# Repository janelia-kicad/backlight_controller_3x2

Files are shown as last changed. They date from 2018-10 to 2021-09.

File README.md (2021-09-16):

- [Repository Information](#org4660580)
  - [Description](#org6dcabe7)
- [Images](#org285c25f)
- [Schematic](#orgf1630ab)
- [Gerbers](#org91c6de4)
- [Bill of Materials](#orgdd32f43)
  - [PCB Parts](#org0175e16)
  - [Supplemental Parts](#orgda2eed9)
  - [Vendor Parts Lists](#orgb926b52)
- [Supplemental Documentation](#org7f741fd)
  - [Assembly Instructions](#orgb29884f)

# Repository Information

-   **Name:** backlight\_controller\_3x2
-   **Version:** 1.2
-   **License:** Open-Source Hardware
-   **URL:** <https://github.com/janelia-kicad/backlight_controller_3x2>
-   **Author:** Peter Polidoro
-   **Email:** peter@polidoro.io

## Description

This board controls one Smart Vision backlight with IR and visible channels plus additional high and low power channel outputs.

# Images

# Schematic

[./schematic/backlight\_controller\_3x2.pdf](./schematic/backlight_controller_3x2.pdf)

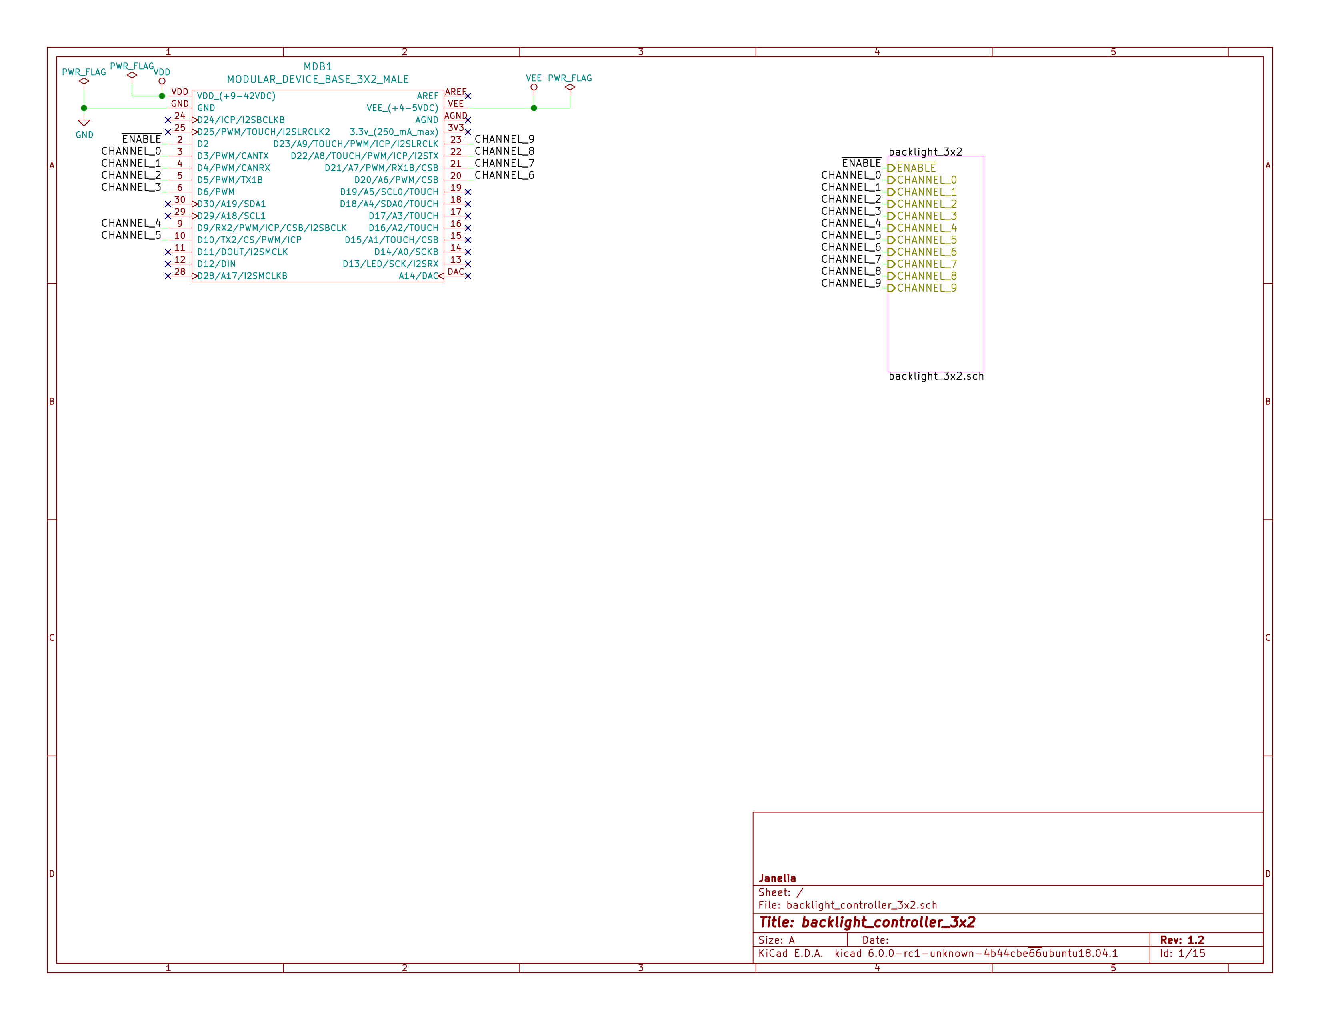
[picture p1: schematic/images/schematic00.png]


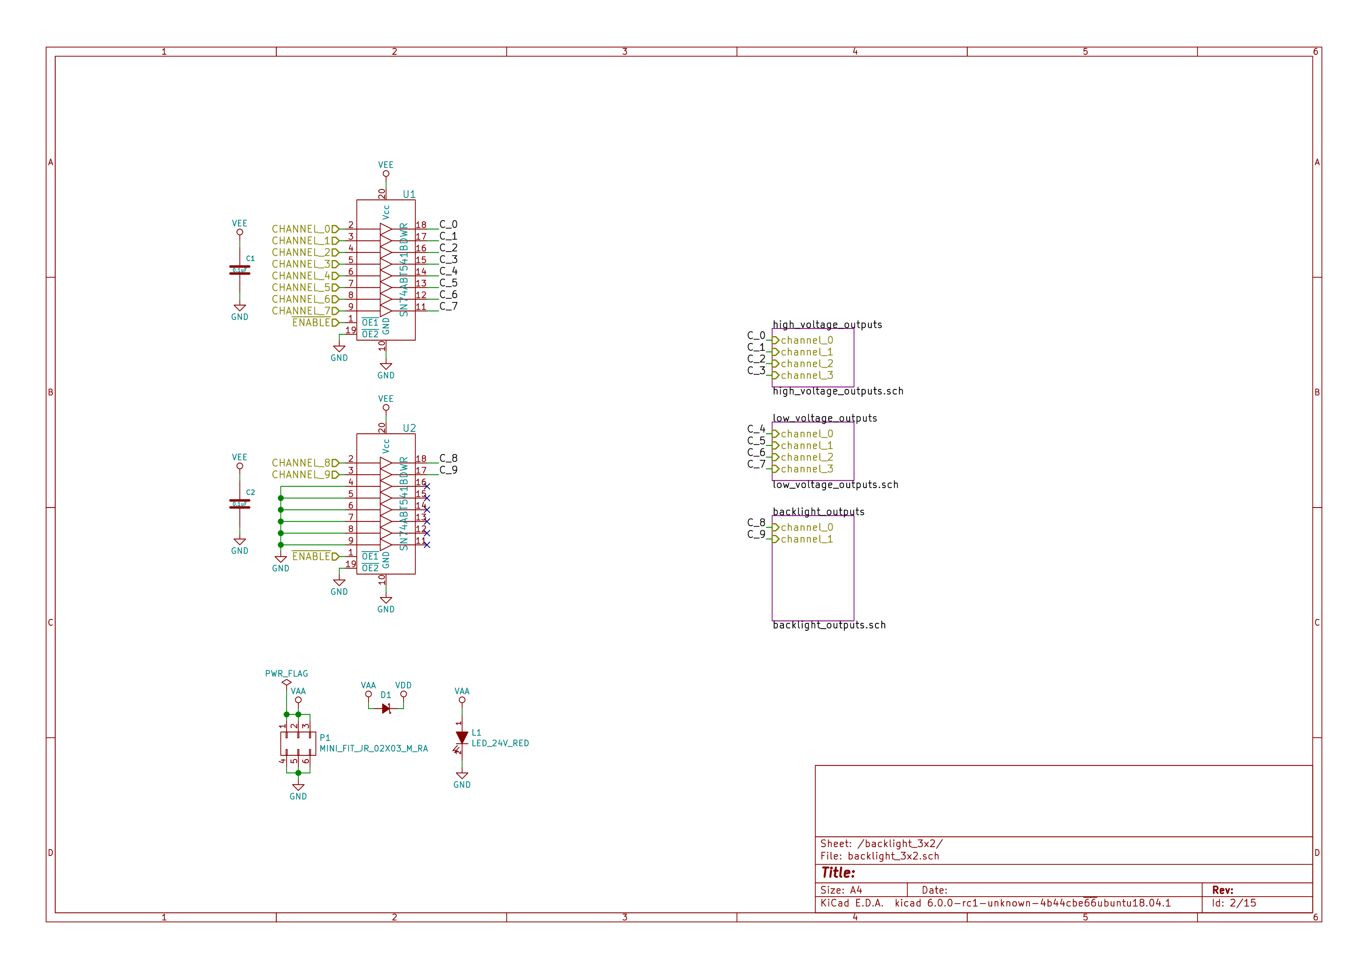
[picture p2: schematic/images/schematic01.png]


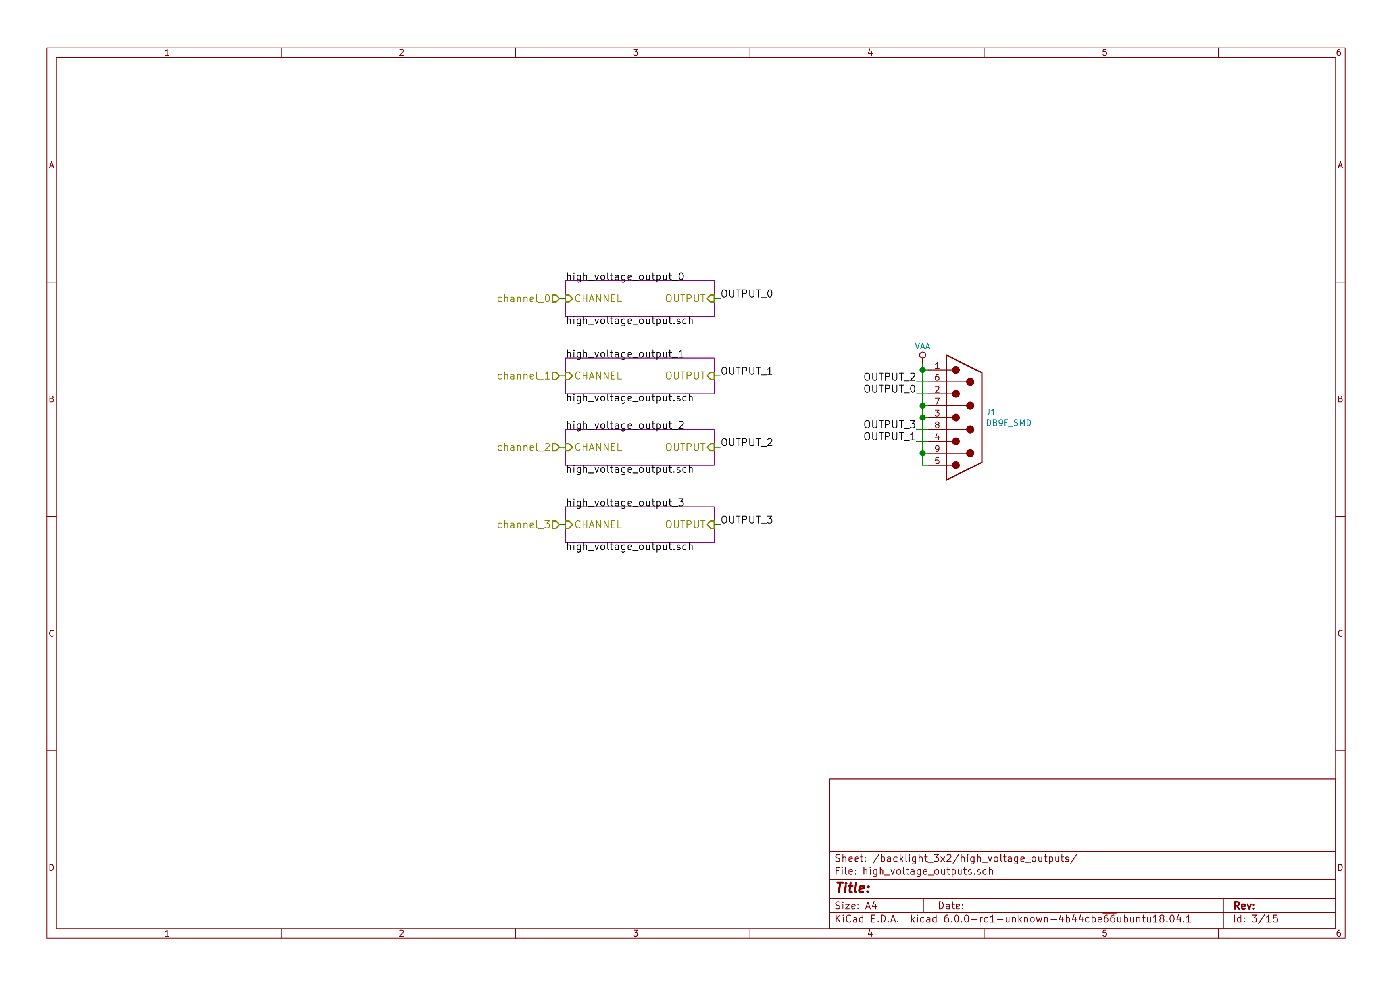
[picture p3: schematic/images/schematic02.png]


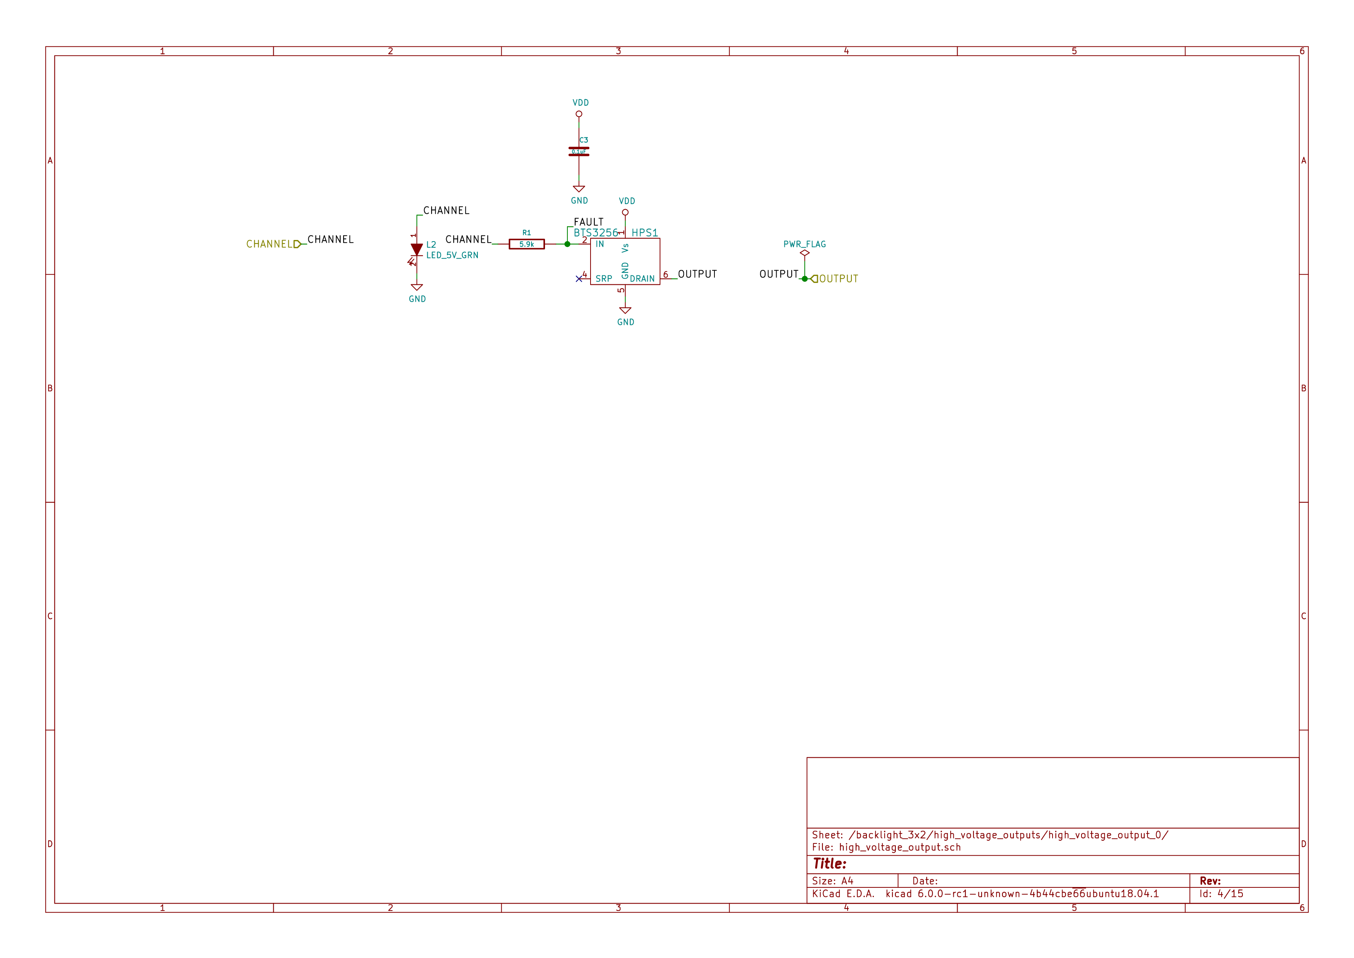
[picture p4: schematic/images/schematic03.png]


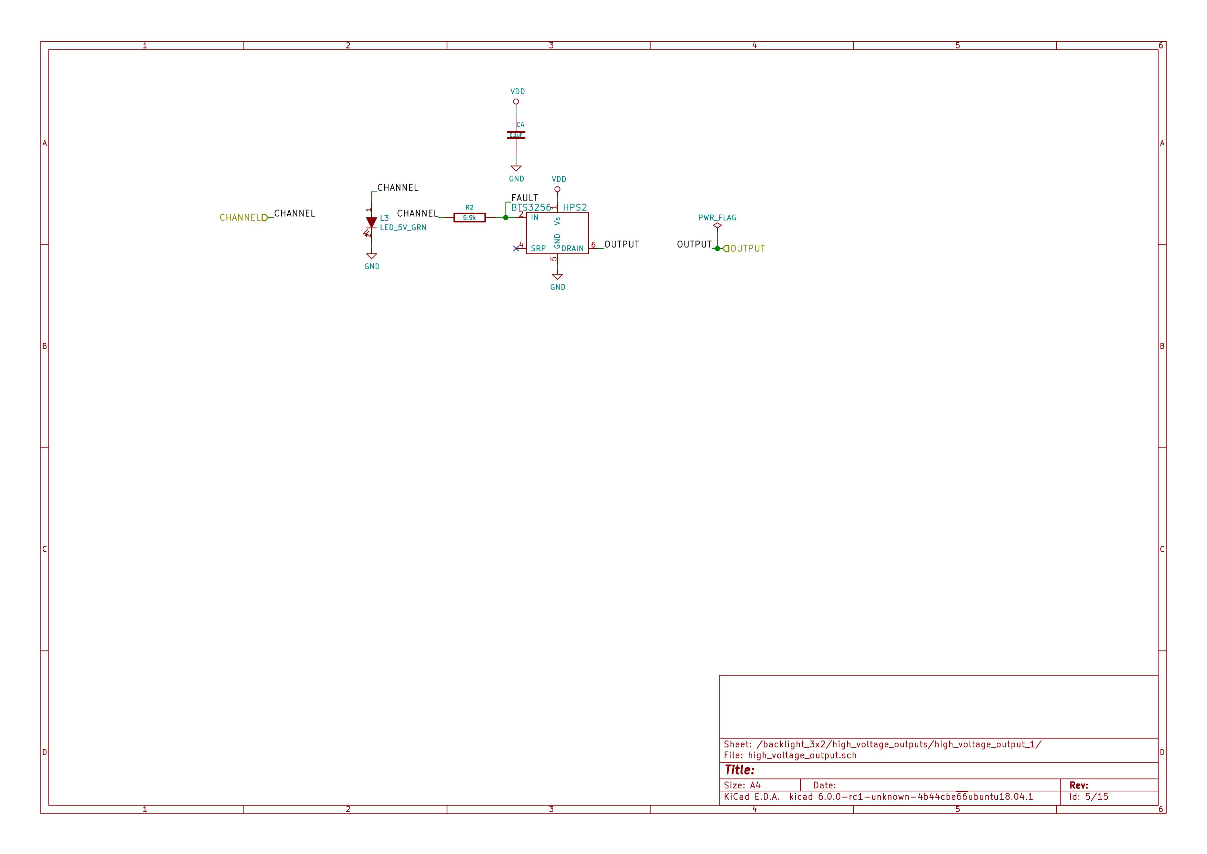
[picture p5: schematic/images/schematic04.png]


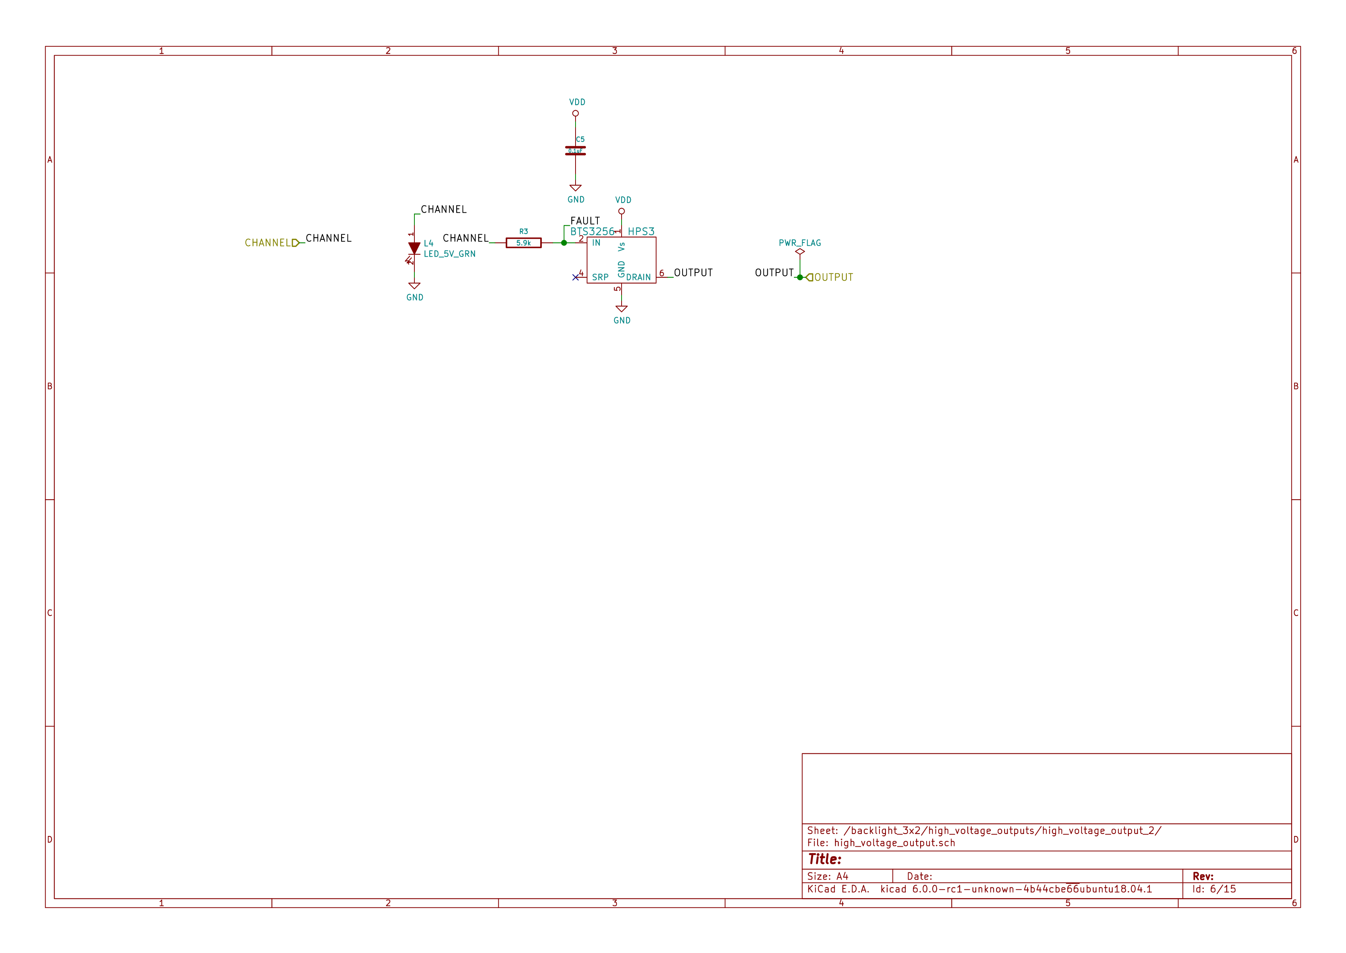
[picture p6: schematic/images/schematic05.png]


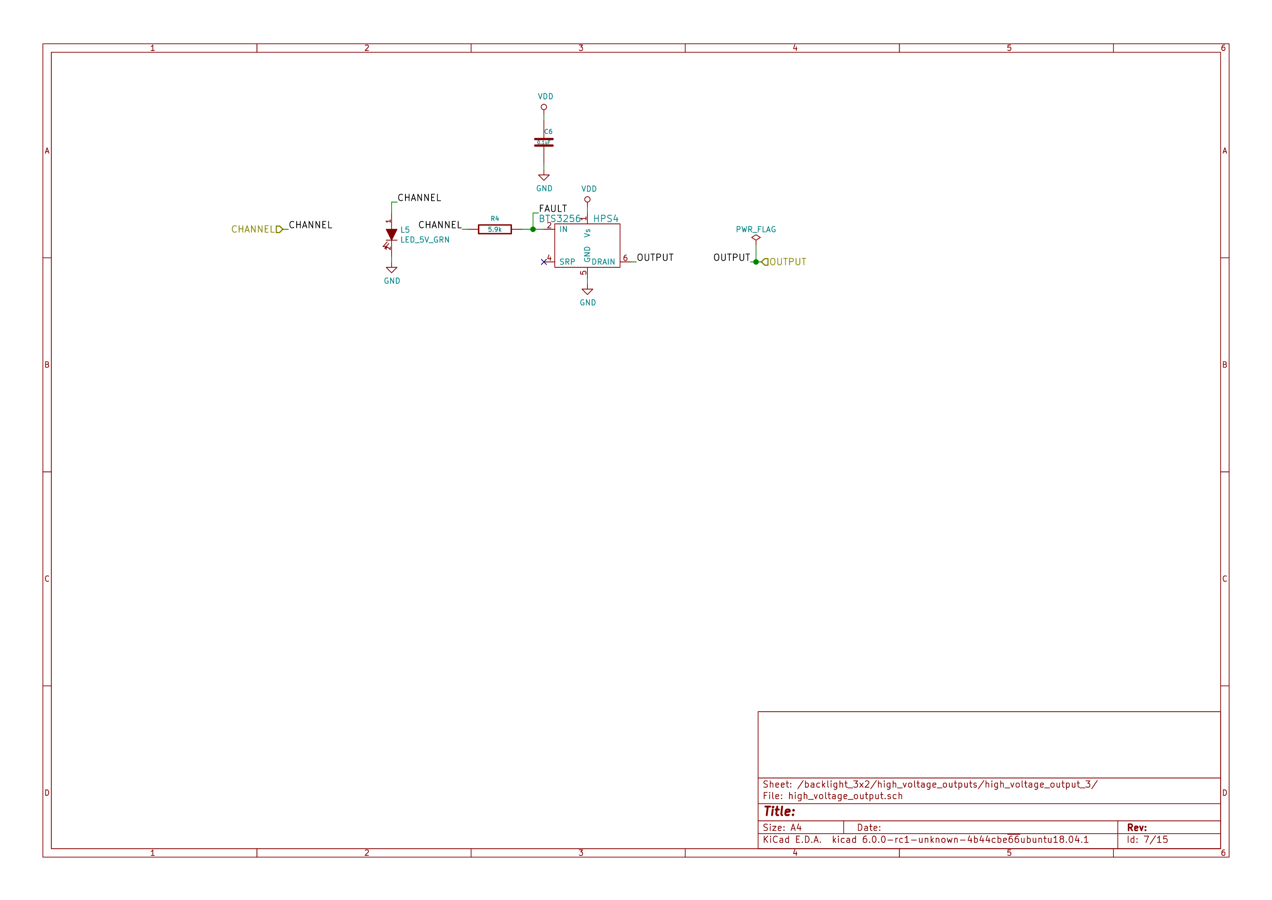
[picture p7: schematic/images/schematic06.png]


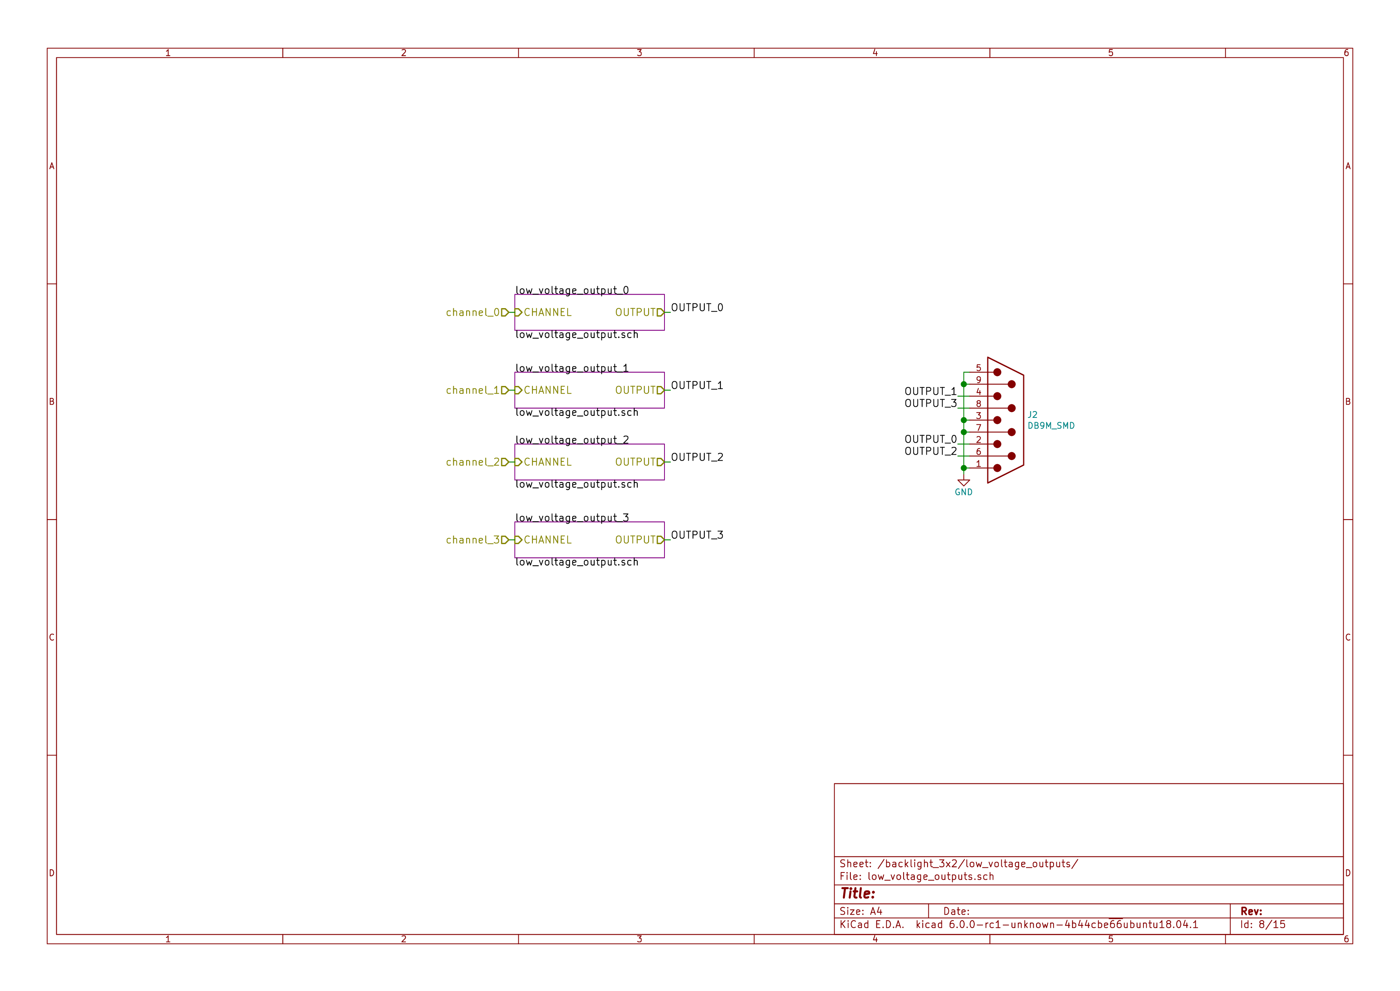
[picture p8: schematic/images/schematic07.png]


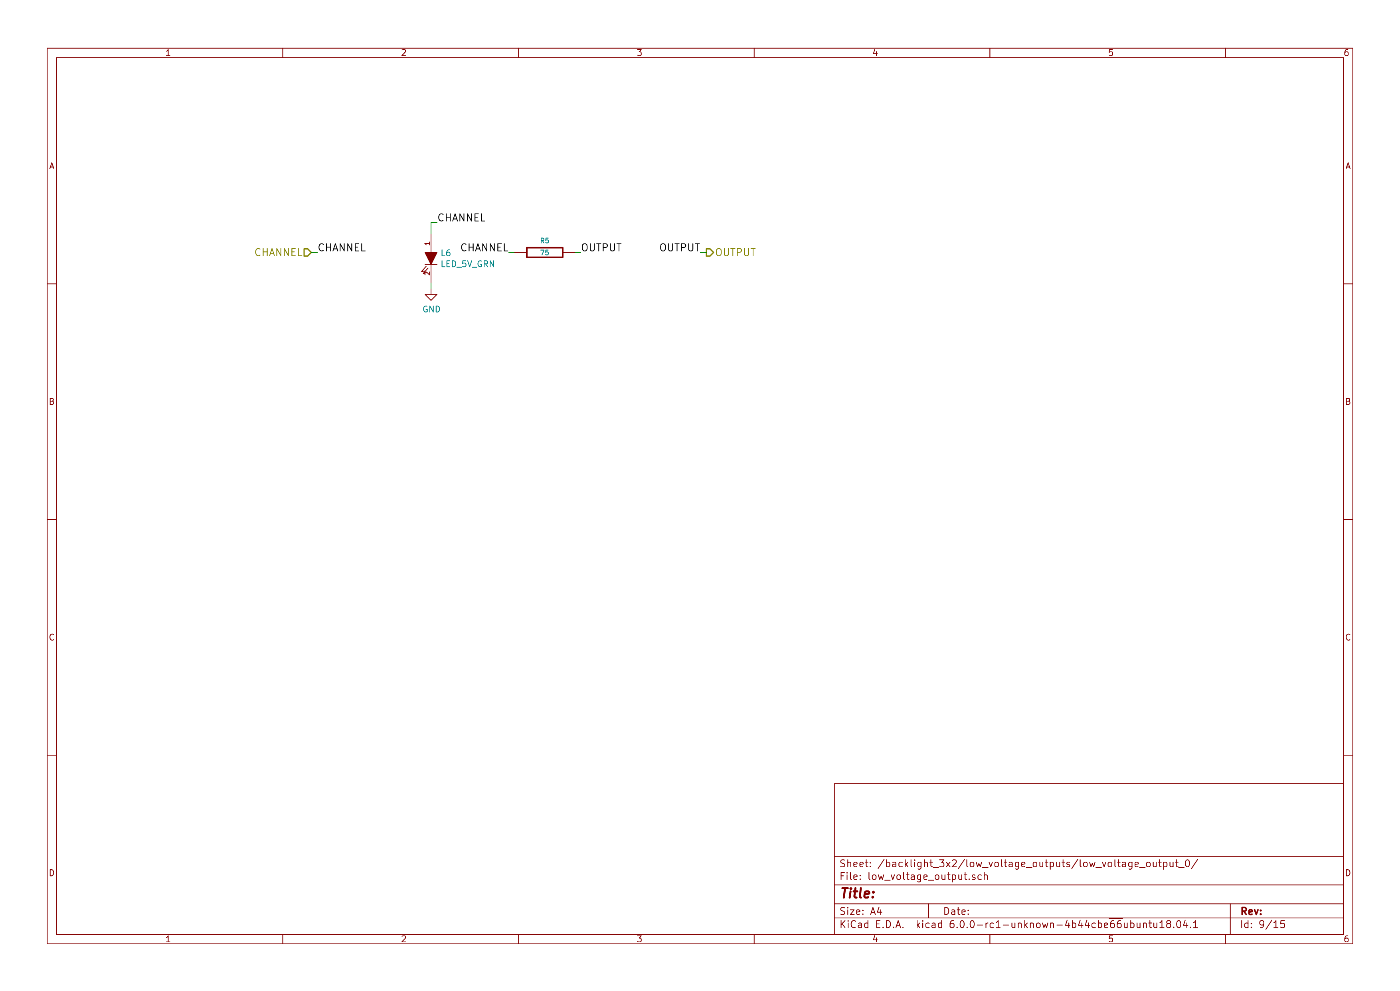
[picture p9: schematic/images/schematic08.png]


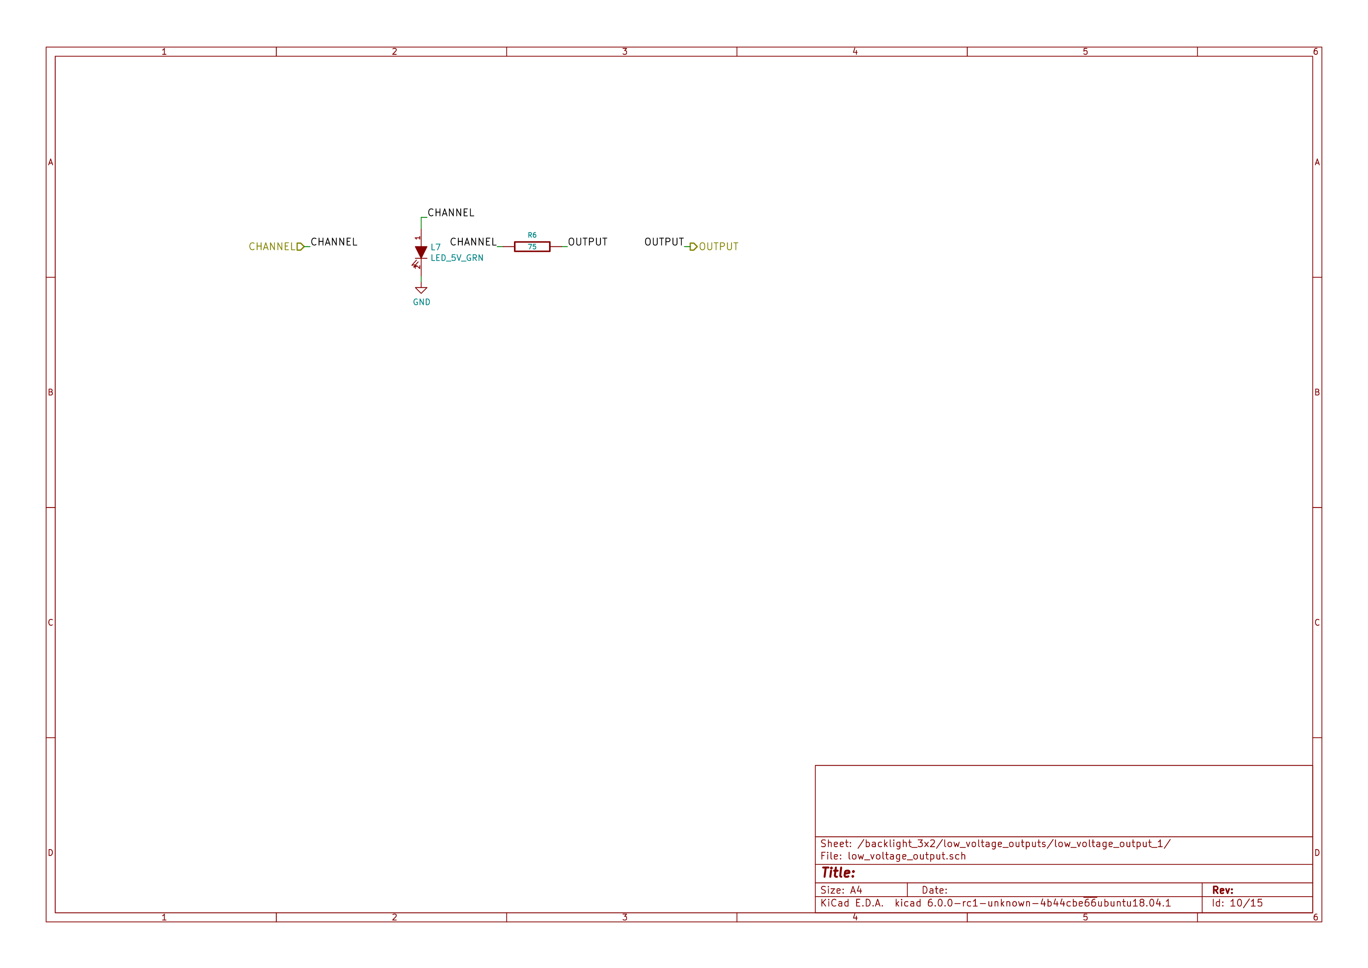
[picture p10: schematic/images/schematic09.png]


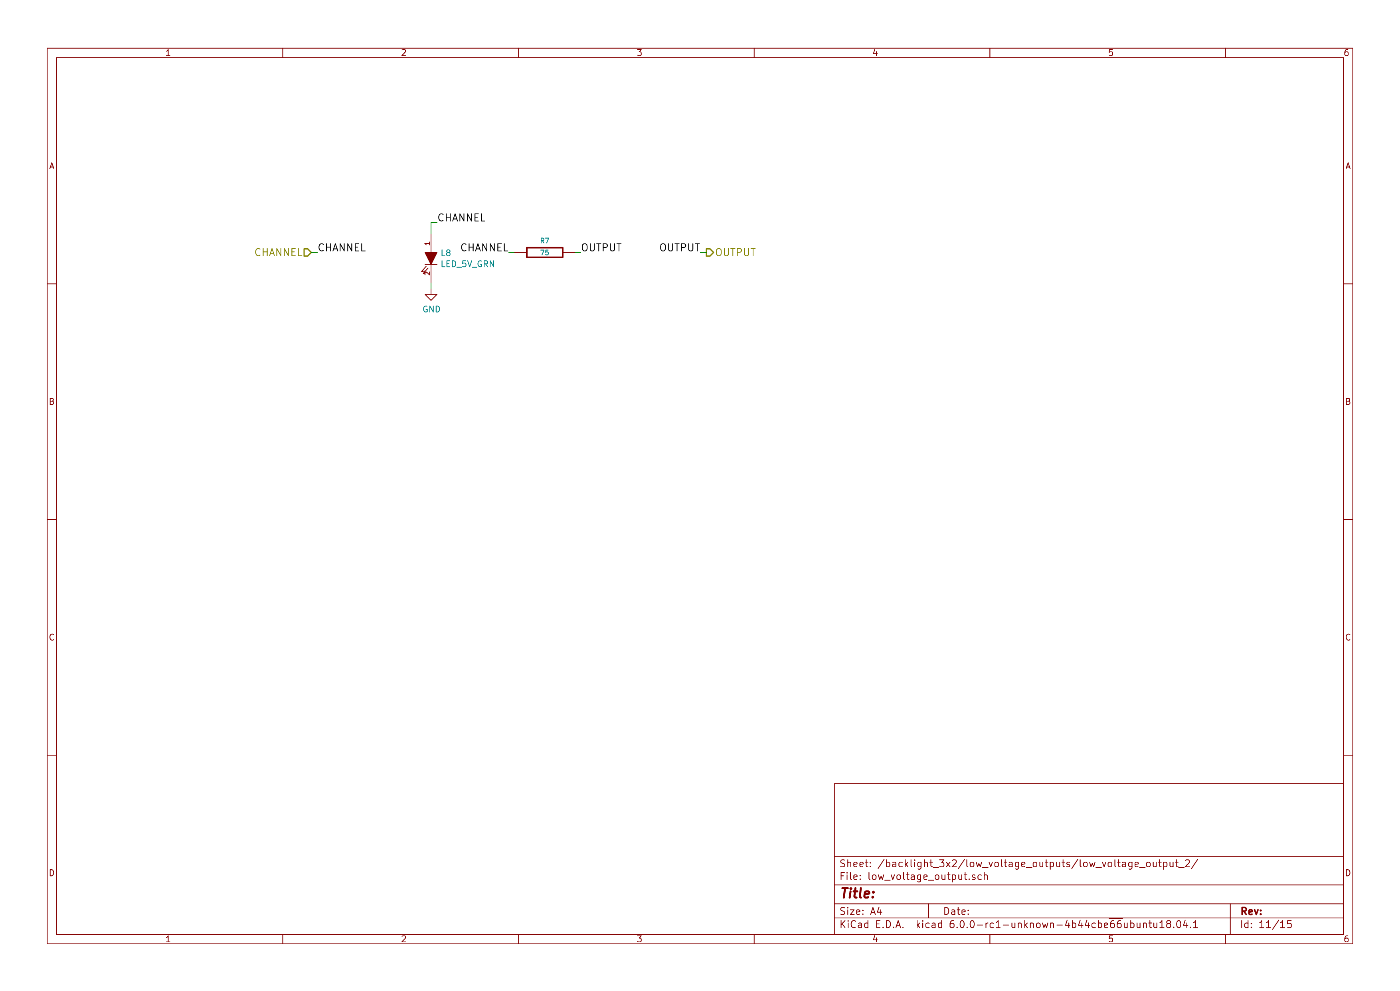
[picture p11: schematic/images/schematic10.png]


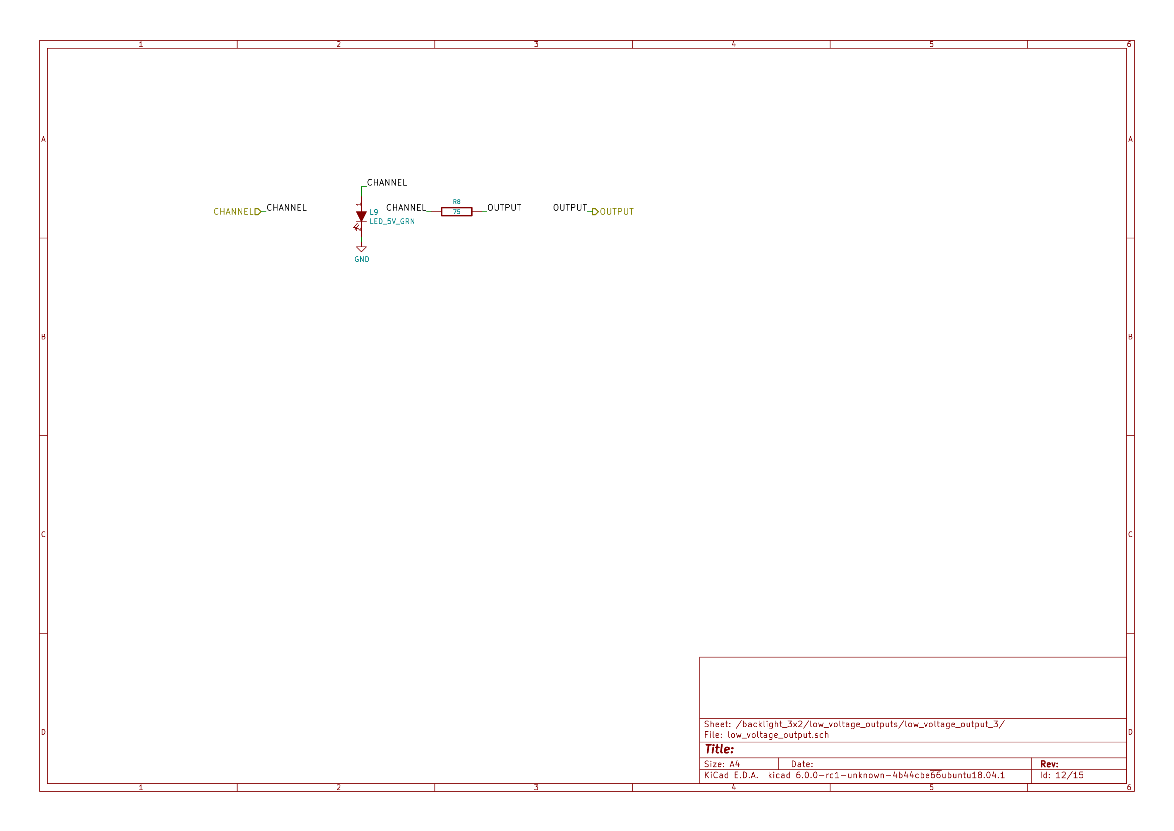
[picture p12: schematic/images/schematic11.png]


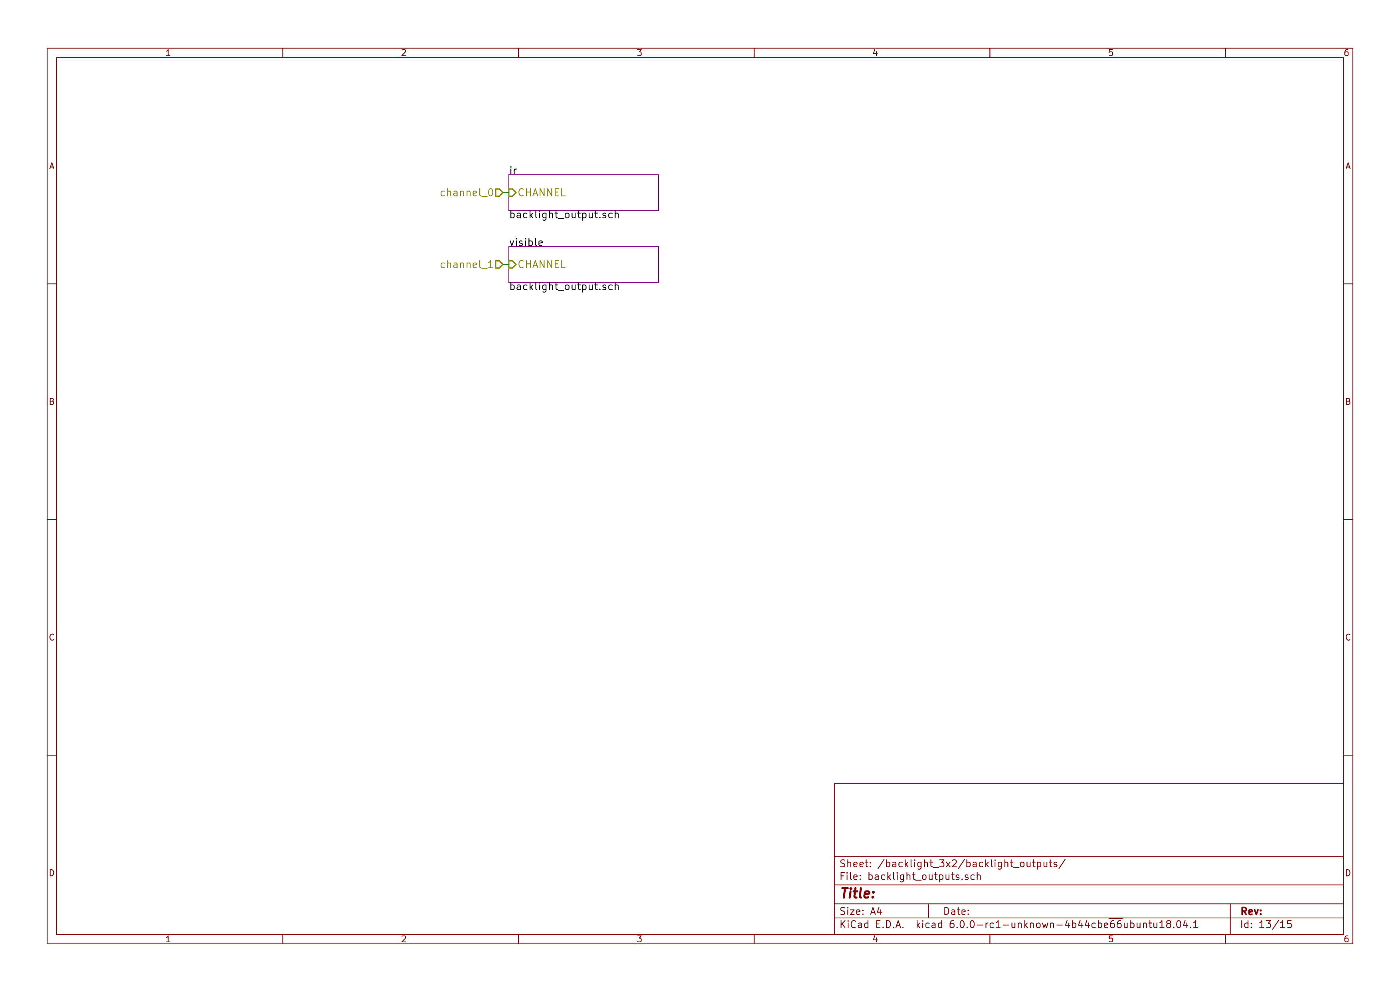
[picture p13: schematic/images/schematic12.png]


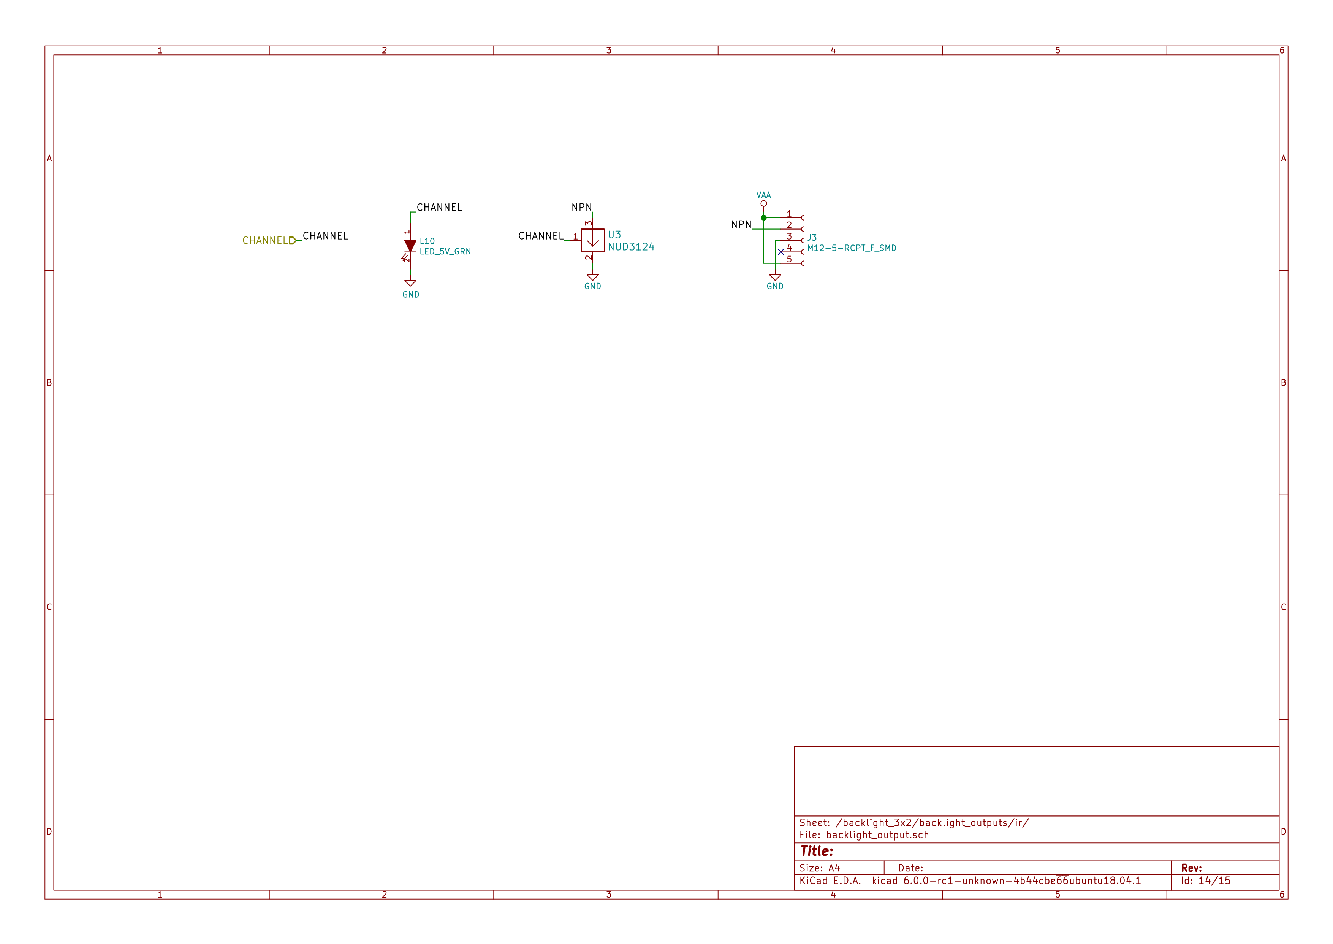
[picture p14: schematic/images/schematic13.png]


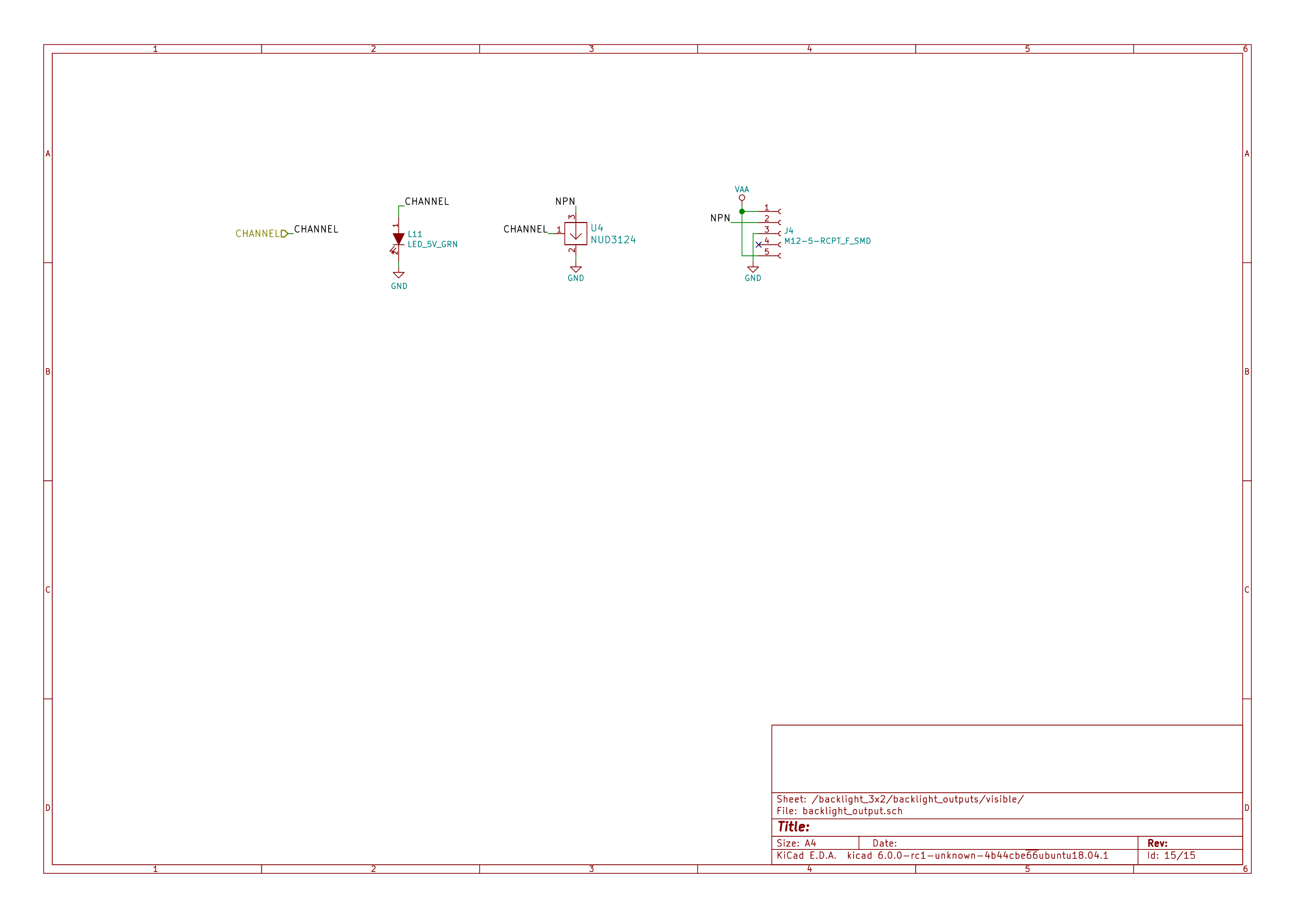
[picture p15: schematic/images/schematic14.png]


# Gerbers

Send gerbers zip file to your favorite PCB manufacturer for fabrication.

[./gerbers/backlight\_controller\_3x2\_v1.2.zip](./gerbers/backlight_controller_3x2_v1.2.zip)

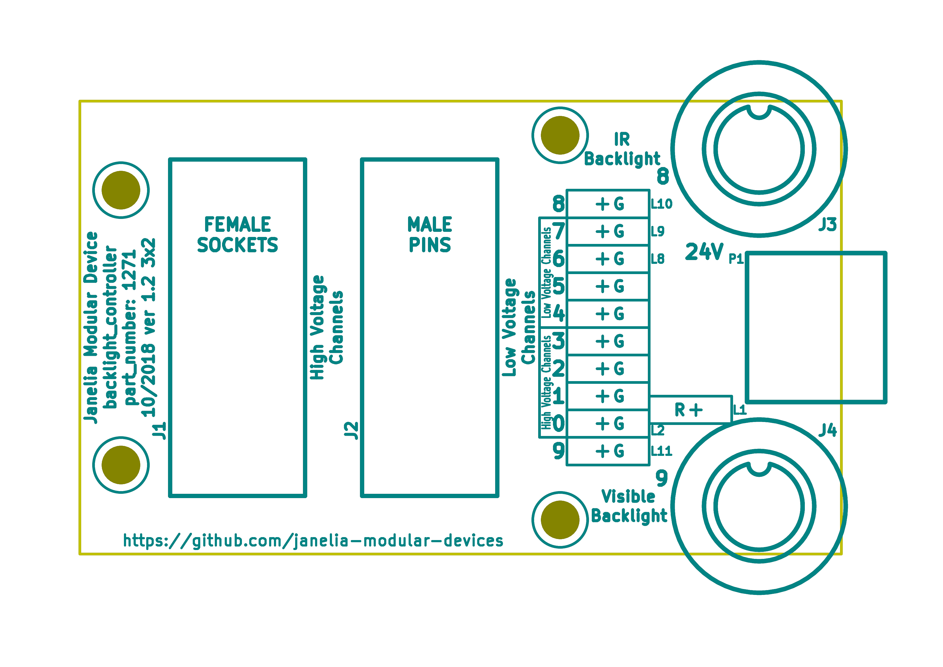
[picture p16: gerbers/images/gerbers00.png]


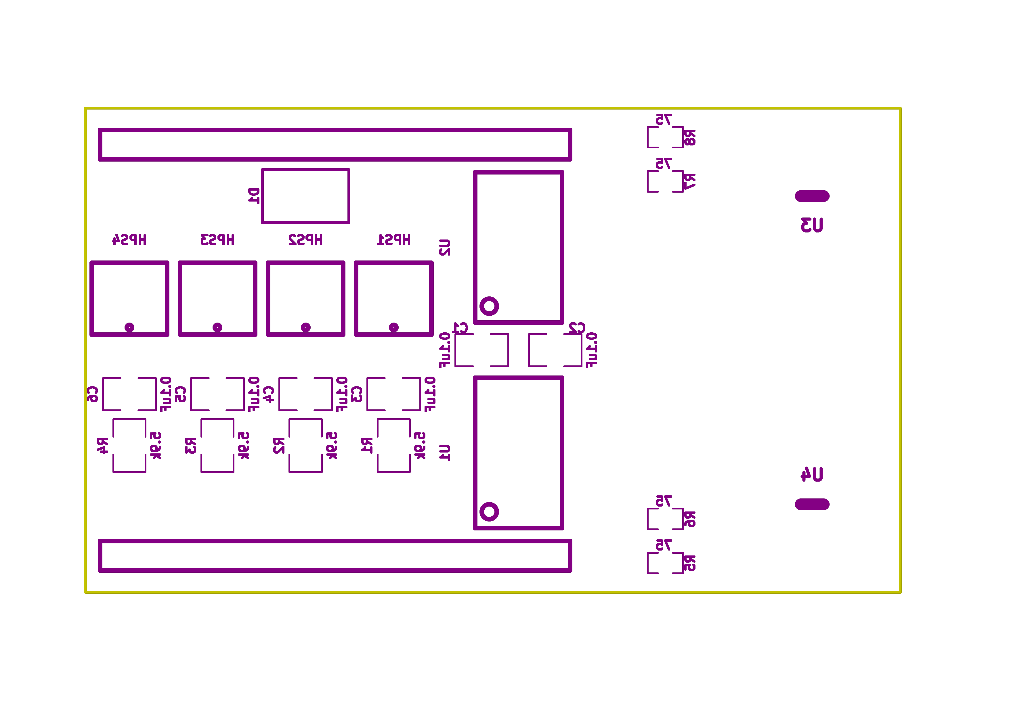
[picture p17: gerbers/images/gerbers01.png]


# Bill of Materials

## PCB Parts

| Item | Reference(s) | Quantity | PartNumber | Vendor  | Description |
|---- |--- |--- |--- |--- |--- |
| 1 | C1 C2 C3 C4 C5 C6 | 6 | 399-13229-1-ND | digikey | CAP CER 0.1UF 50V 10% X7R 1210 |
| 2 | D1 | 1 | 568-11697-1-ND | digikey | DIODE SCHOTTKY 45V 10A CFP15 |
| 3 | HPS1 HPS2 HPS3 HPS4 | 4 | BTS3256DAUMA1CT-ND | digikey | IC SWITCH SMART LOWSIDE TO252-5 |
| 4 | J1 | 1 | 1195-4005-1-ND | digikey | CONN D-SUB RCPT 9POS SMD SOLDER |
| 5 | J2 | 1 | 1195-4006-1-ND | digikey | CONN D-SUB PLUG 9POS SMD SOLDER |
| 6 | J3 J4 | 2 | 277-10282-1-ND | digikey | CONN FMALE INSERT 5POS SOLDER |
| 7 | L1 | 1 | 350-1723-ND | digikey | LED 2MM 24V VERTICAL RED PC MNT |
| 8 | L10 L11 L2 L3 L4 L5 L6 L7 L8 L9 | 10 | 350-1726-ND | digikey | LED 2MM 5V VERTICAL GREEN PC MNT |
| 9 | MDB1 | 2 | S1011E-16-ND | digikey | 16 Position Header Through Hole Male Pins |
| 10 | P1 | 1 | WM1353-ND | digikey | CONN HEADER 6POS 4.2MM R/A TIN |
| 11 | R1 R2 R3 R4 | 4 | P5.90KAACT-ND | digikey | RES SMD 5.9k OHM 1% 1/2W 1210 |
| 12 | R5 R6 R7 R8 | 4 | P75.0CCT-ND | digikey | RES SMD 75 OHM 1% 1/8W 0805 |
| 13 | U1 U2 | 2 | 296-14668-1-ND | digikey | Buffer Non-Inverting 1 Element 8 Bit per Element Push-Pull Output 20-SOIC |
| 14 | U3 U4 | 2 | NUD3124LT1GOSCT-ND | digikey | IC INDCT LOAD DRVR AUTO SOT23 |

## Supplemental Parts

| Item | Quantity | PartNumber | Vendor  | Description |
|---- |--- |--- |--- |--- |
| 1 | 1 | 1866-2122-ND | digikey | AC/DC DESKTOP ADAPTER 24V 280W |
| 2 | 1 | 1866-5006-ND | digikey | CORD IEC 320-C13 6FT BLACK |
| 3 | 2 | 277-10308-ND | digikey | CONN INSERT SHELL PRESS FIT |

## Vendor Parts Lists

[./bom/digikey\_parts.csv](./bom/digikey_parts.csv)

[./bom/supplemental\_digikey\_parts.csv](./bom/supplemental_digikey_parts.csv)

# Supplemental Documentation

## Assembly Instructions

-   Solder surface mount and through hole components onto the pcb.

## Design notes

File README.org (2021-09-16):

# Created 2018-10-29 Mon 13:45
#+OPTIONS: title:nil author:nil email:nil toc:t |:t ^:nil
* Repository Information

- Name :: backlight_controller_3x2
- Version :: 1.2
- License :: Open-Source Hardware
- URL :: https://github.com/janelia-kicad/backlight_controller_3x2
- Author :: Peter Polidoro
- Email :: peter@polidoro.io

** Description

This board controls one Smart Vision backlight with IR and visible channels
plus additional high and low power channel outputs.

* Images

* Schematic

[[file:./schematic/backlight_controller_3x2.pdf][./schematic/backlight_controller_3x2.pdf]]































* Gerbers

Send gerbers zip file to your favorite PCB manufacturer for fabrication.

[[file:./gerbers/backlight_controller_3x2_v1.2.zip][./gerbers/backlight_controller_3x2_v1.2.zip]]





* Bill of Materials

** PCB Parts

| Item | Reference(s)                    | Quantity | PartNumber         | Vendor  | Description                                                               |
|------+---------------------------------+----------+--------------------+---------+---------------------------------------------------------------------------|
|    1 | C1 C2 C3 C4 C5 C6               |        6 | 399-13229-1-ND     | digikey | CAP CER 0.1UF 50V 10% X7R 1210                                            |
|    2 | D1                              |        1 | 568-11697-1-ND     | digikey | DIODE SCHOTTKY 45V 10A CFP15                                              |
|    3 | HPS1 HPS2 HPS3 HPS4             |        4 | BTS3256DAUMA1CT-ND | digikey | IC SWITCH SMART LOWSIDE TO252-5                                           |
|    4 | J1                              |        1 | 1195-4005-1-ND     | digikey | CONN D-SUB RCPT 9POS SMD SOLDER                                           |
|    5 | J2                              |        1 | 1195-4006-1-ND     | digikey | CONN D-SUB PLUG 9POS SMD SOLDER                                           |
|    6 | J3 J4                           |        2 | 277-10282-1-ND     | digikey | CONN FMALE INSERT 5POS SOLDER                                             |
|    7 | L1                              |        1 | 350-1723-ND        | digikey | LED 2MM 24V VERTICAL RED PC MNT                                           |
|    8 | L10 L11 L2 L3 L4 L5 L6 L7 L8 L9 |       10 | 350-1726-ND        | digikey | LED 2MM 5V VERTICAL GREEN PC MNT                                          |
|    9 | MDB1                            |        2 | S1011E-16-ND       | digikey | 16 Position Header Through Hole Male Pins                                 |
|   10 | P1                              |        1 | WM1353-ND          | digikey | CONN HEADER 6POS 4.2MM R/A TIN                                            |
|   11 | R1 R2 R3 R4                     |        4 | P5.90KAACT-ND      | digikey | RES SMD 5.9k OHM 1% 1/2W 1210                                             |
|   12 | R5 R6 R7 R8                     |        4 | P75.0CCT-ND        | digikey | RES SMD 75 OHM 1% 1/8W 0805                                               |
|   13 | U1 U2                           |        2 | 296-14668-1-ND     | digikey | Buffer Non-Inverting 1 Element 8 Bit per Element Push-Pull Output 20-SOIC |
|   14 | U3 U4                           |        2 | NUD3124LT1GOSCT-ND | digikey | IC INDCT LOAD DRVR AUTO SOT23                                             |

** Supplemental Parts

| Item | Quantity | PartNumber   | Vendor  | Description                    |
|------+----------+--------------+---------+--------------------------------|
|    1 |        1 | 1866-2122-ND | digikey | AC/DC DESKTOP ADAPTER 24V 280W |
|    2 |        1 | 1866-5006-ND | digikey | CORD IEC 320-C13 6FT BLACK     |
|    3 |        2 | 277-10308-ND | digikey | CONN INSERT SHELL PRESS FIT    |

** Vendor Parts Lists

[[file:./bom/digikey_parts.csv][./bom/digikey_parts.csv]]

[[file:./bom/supplemental_digikey_parts.csv][./bom/supplemental_digikey_parts.csv]]

* Supplemental Documentation

** Assembly Instructions

- Solder surface mount and through hole components onto the pcb.

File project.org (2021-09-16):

* Header                                                           :noexport:

  #+MACRO: name backlight_controller_3x2
  #+MACRO: version 1.2
  #+MACRO: license Open-Source Hardware
  #+MACRO: url https://github.com/janelia-kicad/backlight_controller_3x2
  #+AUTHOR: Peter Polidoro
  #+EMAIL: peter@polidoro.io

* Description

  This board controls one Smart Vision backlight with IR and visible channels
  plus additional high and low power channel outputs.

* Assembly Instructions

  - Solder surface mount and through hole components onto the pcb.

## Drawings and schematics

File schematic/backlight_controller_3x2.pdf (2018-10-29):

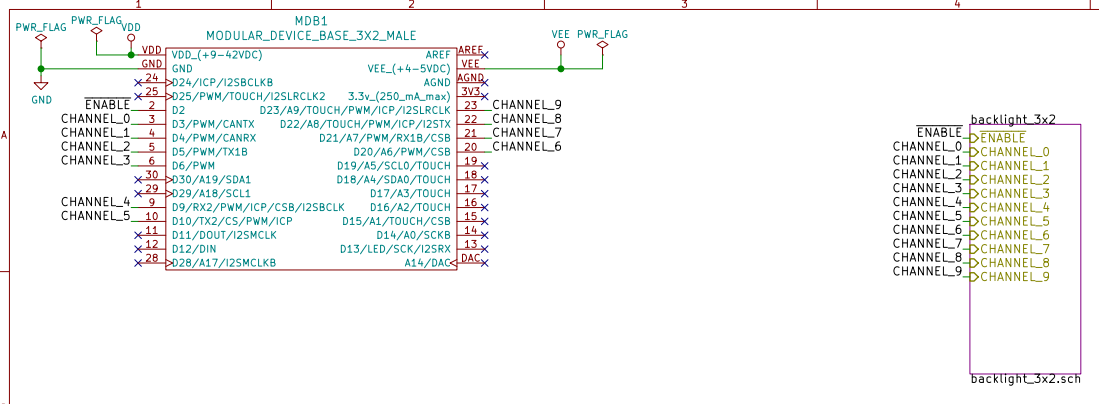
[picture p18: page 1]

File: backlight_controller_3x2.sch Sheet: / Janelia

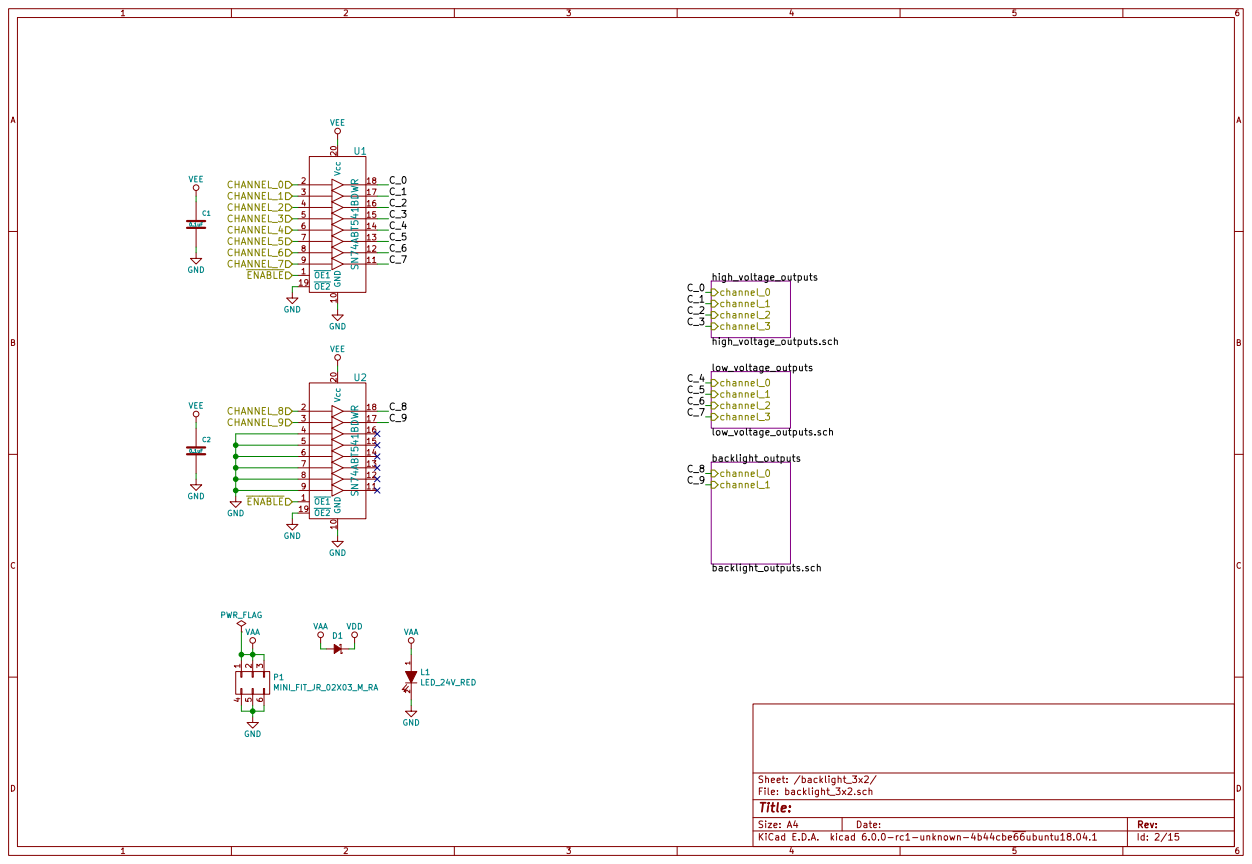
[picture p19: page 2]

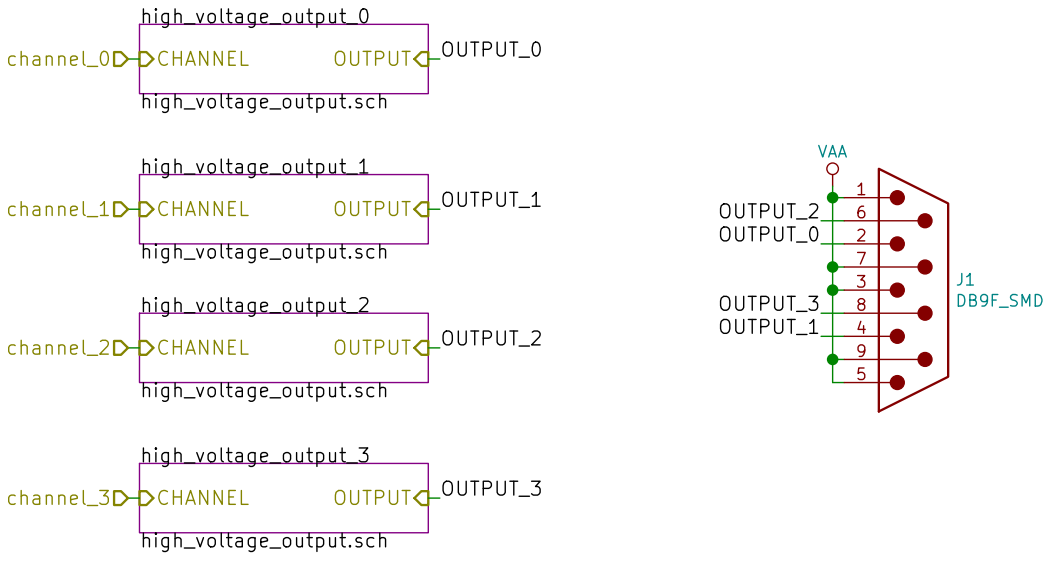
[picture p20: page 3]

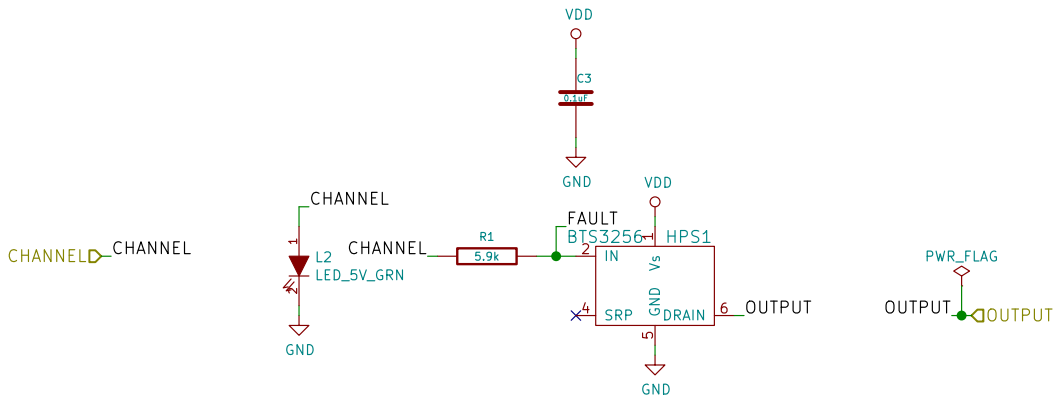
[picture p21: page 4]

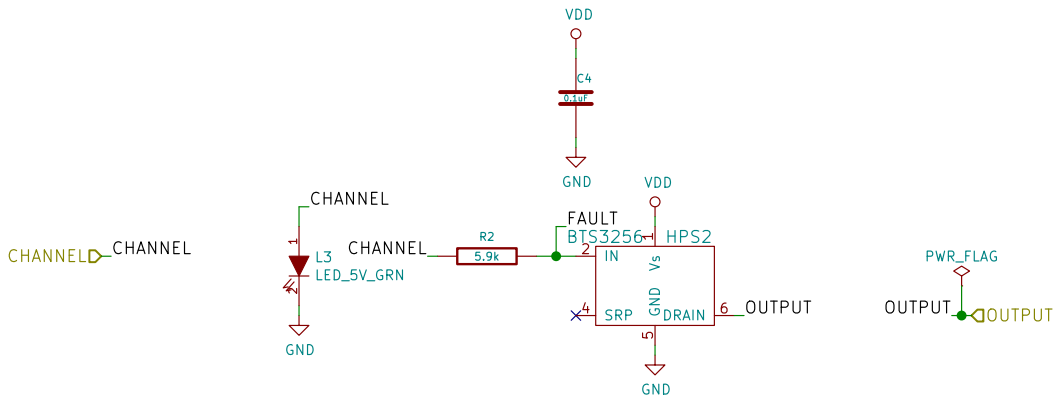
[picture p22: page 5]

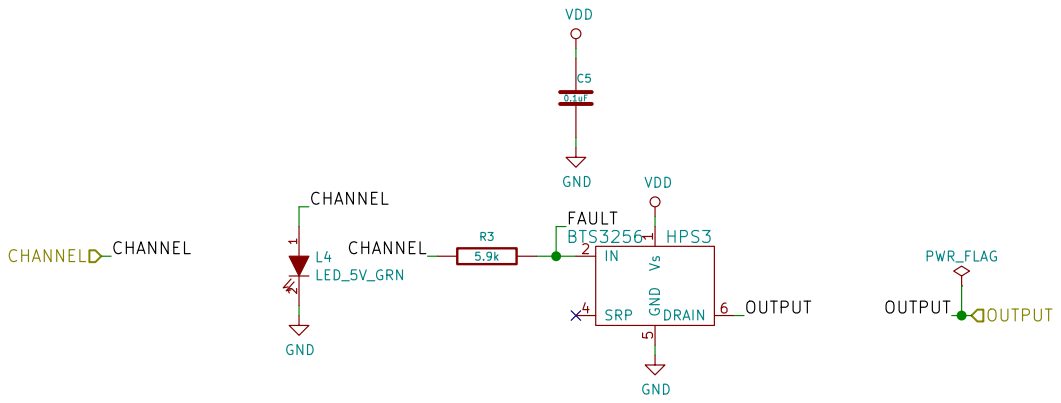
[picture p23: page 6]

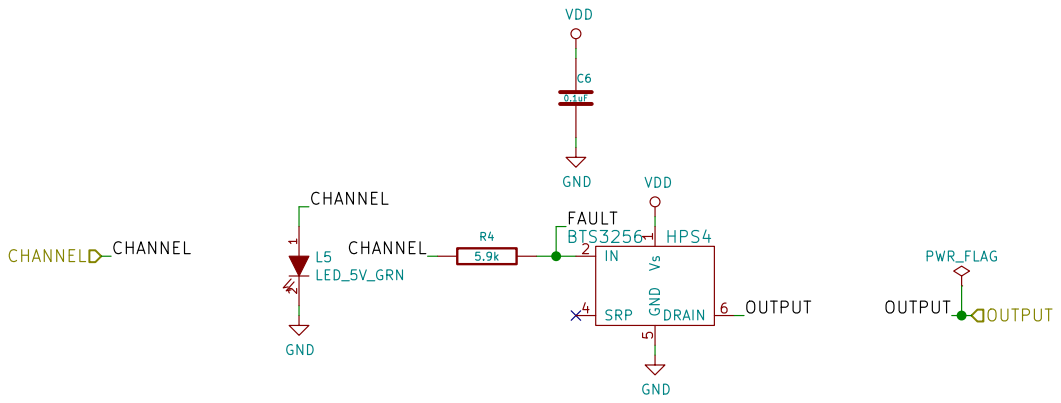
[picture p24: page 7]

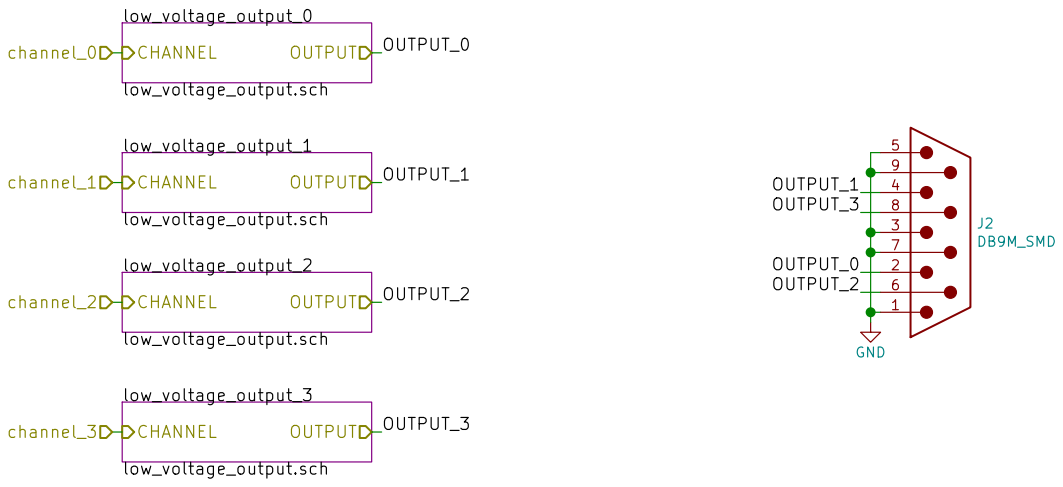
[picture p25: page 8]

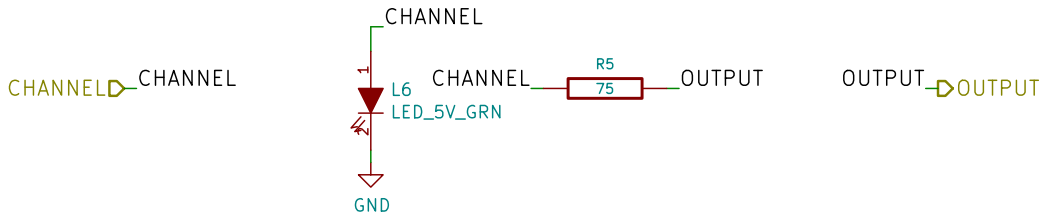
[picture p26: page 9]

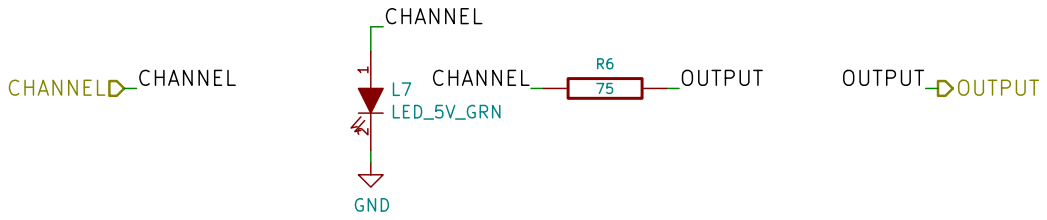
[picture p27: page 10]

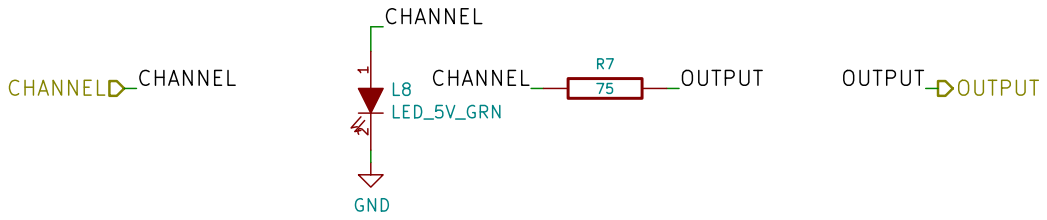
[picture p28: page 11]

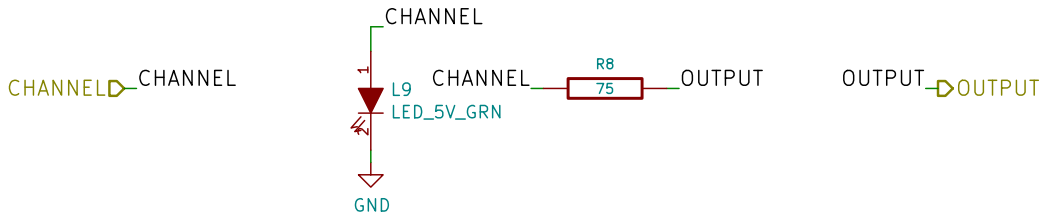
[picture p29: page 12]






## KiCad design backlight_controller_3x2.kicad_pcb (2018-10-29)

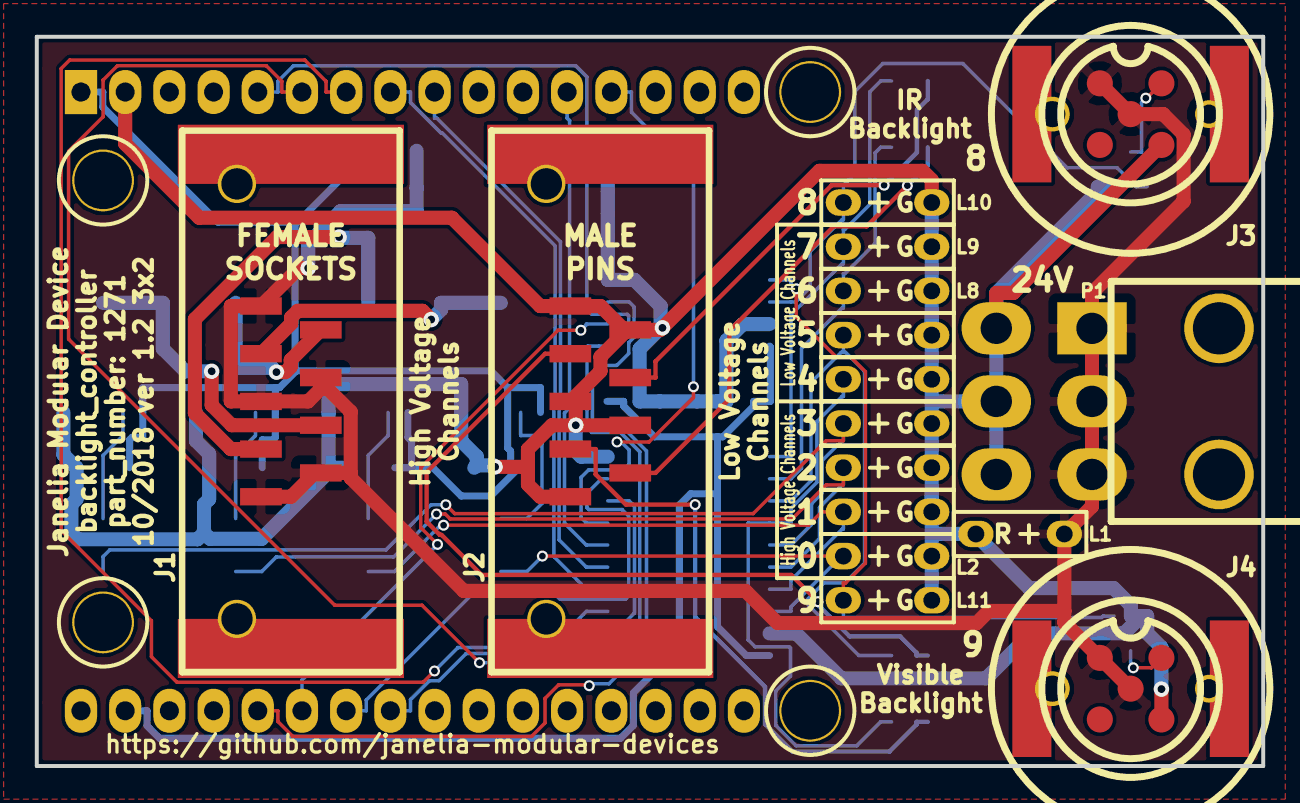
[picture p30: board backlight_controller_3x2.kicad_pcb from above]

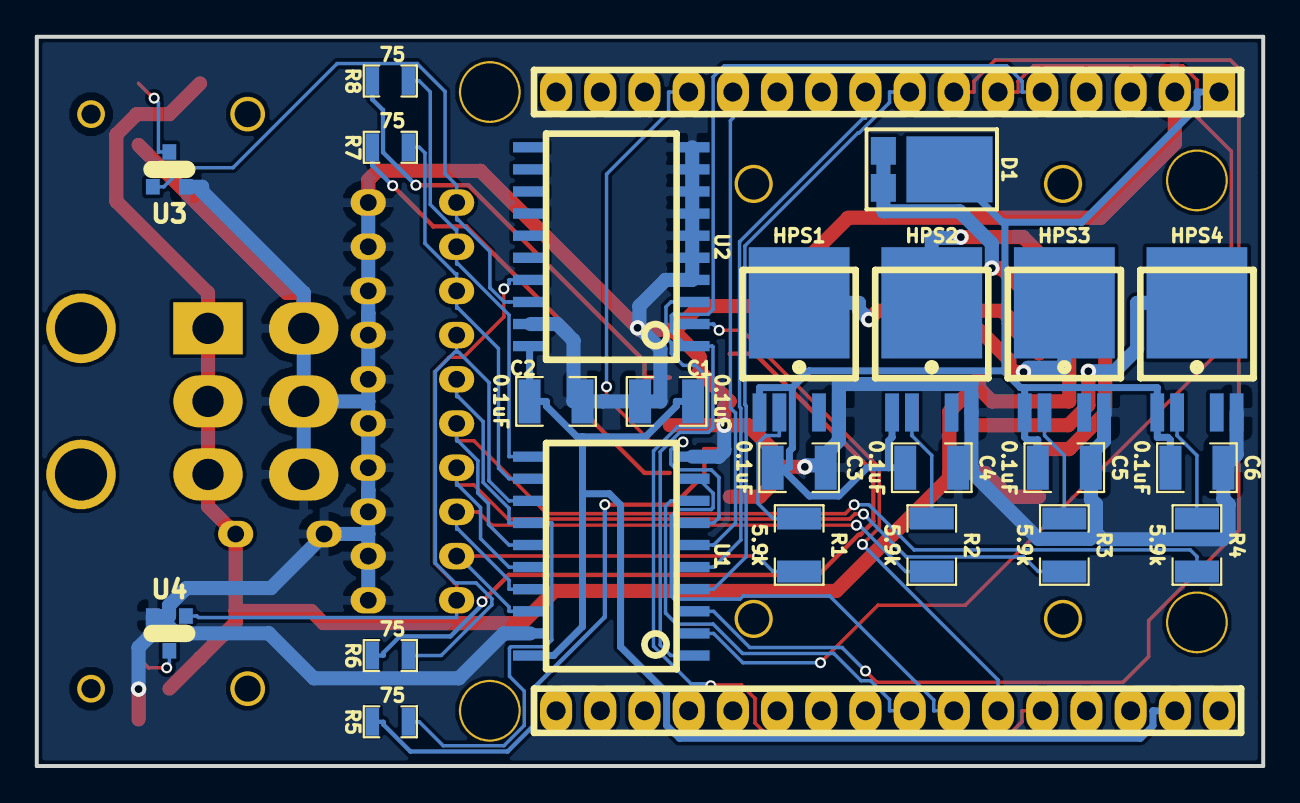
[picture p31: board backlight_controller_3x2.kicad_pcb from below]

Board: 2 copper layers, 70.5 x 41.9 mm, 40 parts (23 on the bottom side), 39 nets.

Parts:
C1, C2, C3, C4, C5, C6: 0.1uF; SM1210
D1: diode_schottky_45V_10A; CFP15
HPS1, HPS2, HPS3, HPS4: BTS3256; PG-TO252-5-11
J1: DB9F_SMD
J2: DB9M_SMD
J3, J4: M12-5-RCPT_F_SMD; M12-5_RCPT_F_SMD
L1: LED_24V_RED; LED_555-3XXX_R
L2, L3, L4, L5, L6, L7, L8, L9, L10, L11: LED_5V_GRN; LED_555-3XXX_G
MDB1: MODULAR_DEVICE_BASE_3X2_MALE
P1: MINI_FIT_JR_02X03_M_RA; MINI-FIT-JR_02X03_M_RA
R1, R2, R3, R4: 5.9k; SM1210
R5, R6, R7, R8: 75; SM0805
U1, U2: SN74ABT541BDWR; SOIC_20
U3, U4: NUD3124; TO-236-3

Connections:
/CHANNEL_0: MDB1.3, U1.2
/CHANNEL_1: MDB1.4, U1.3
/CHANNEL_2: MDB1.5, U1.4
/CHANNEL_3: MDB1.6, U1.5
/CHANNEL_4: MDB1.9, U1.6
/CHANNEL_5: MDB1.10, U1.7
/CHANNEL_6: MDB1.20, U1.8
/CHANNEL_7: MDB1.21, U1.9
/CHANNEL_8: MDB1.22, U2.2
/CHANNEL_9: MDB1.23, U2.3
/backlight_3x2/C_0: L2.1, R1.2, U1.18
/backlight_3x2/C_1: L3.1, R2.2, U1.17
/backlight_3x2/C_2: L4.1, R3.2, U1.16
/backlight_3x2/C_3: L5.1, R4.2, U1.15
/backlight_3x2/C_4: L6.1, R5.2, U1.14
/backlight_3x2/C_5: L7.1, R6.2, U1.13
/backlight_3x2/C_6: L8.1, R7.2, U1.12
/backlight_3x2/C_7: L9.1, R8.2, U1.11
/backlight_3x2/C_8: L10.1, U2.18, U3.1
/backlight_3x2/C_9: L11.1, U2.17, U4.1
/backlight_3x2/backlight_outputs/ir/NPN: J3.2, U3.3
/backlight_3x2/backlight_outputs/visible/NPN: J4.2, U4.3
/backlight_3x2/high_voltage_outputs/OUTPUT_0: HPS1.6, J1.2
/backlight_3x2/high_voltage_outputs/OUTPUT_1: HPS2.6, J1.4
/backlight_3x2/high_voltage_outputs/OUTPUT_2: HPS3.6, J1.6
/backlight_3x2/high_voltage_outputs/OUTPUT_3: HPS4.6, J1.8
/backlight_3x2/high_voltage_outputs/high_voltage_output_0/FAULT: HPS1.2, R1.1
/backlight_3x2/high_voltage_outputs/high_voltage_output_1/FAULT: HPS2.2, R2.1
/backlight_3x2/high_voltage_outputs/high_voltage_output_2/FAULT: HPS3.2, R3.1
/backlight_3x2/high_voltage_outputs/high_voltage_output_3/FAULT: HPS4.2, R4.1
/backlight_3x2/low_voltage_outputs/OUTPUT_0: J2.2, R5.1
/backlight_3x2/low_voltage_outputs/OUTPUT_1: J2.4, R6.1
/backlight_3x2/low_voltage_outputs/OUTPUT_2: J2.6, R7.1
/backlight_3x2/low_voltage_outputs/OUTPUT_3: J2.8, R8.1
/~ENABLE: MDB1.2, U1.1, U2.1
GND: C1.2, C2.2, C3.2, C4.2, C5.2, C6.2, HPS1.5, HPS2.5, HPS3.5, HPS4.5, J2.1, J2.3, J2.5, J2.7, J2.9, J3.3, J4.3, L1.2, L2.2, L3.2, L4.2, L5.2, L6.2, L7.2, L8.2, L9.2, L10.2, L11.2, MDB1.GND, P1.4, P1.5, P1.6, U1.10, U1.19, U2.4, U2.5, U2.6, U2.7, U2.8, U2.9, U2.10, U2.19, U3.2, U4.2
VAA: D1.2, J1.1, J1.3, J1.5, J1.7, J1.9, J3.1, J3.5, J4.1, J4.5, L1.1, P1.1, P1.2, P1.3
VDD: C3.1, C4.1, C5.1, C6.1, D1.1, HPS1.1, HPS2.1, HPS3.1, HPS4.1, MDB1.VDD
VEE: C1.1, C2.1, MDB1.VEE, U1.20, U2.20

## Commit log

2018-09-13 Initial commit.
    [backlight_controller_3x2.kicad_pcb, backlight_controller_3x2.sch]
2018-09-13 Added components and footprints.
2018-09-13 Added schematics.
    [backlight_3x2.sch, backlight_controller_3x2.sch, backlight_output.sch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]
2018-09-13 Initial layout.
    [backlight_3x2.sch, backlight_controller_3x2.kicad_pcb, backlight_controller_3x2.sch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]
2018-09-13 Finished version 1.0.
    [backlight_controller_3x2.dsn, backlight_controller_3x2.kicad_pcb]
2018-09-14 Moved some pcb text.
    [backlight_controller_3x2.kicad_pcb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]
2018-09-14 Updated documentation.
    [digikey_order.csv, digikey_parts.csv, supplemental_digikey_parts.csv]
2018-10-19 Changes towards v1.1.
    [backlight_3x2.sch, backlight_controller_3x2.kicad_pcb, backlight_controller_3x2.sch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]
2018-10-19 More changes towards v1.1.
    [backlight_output.sch, high_power_output.sch, low_power_outputs.sch]
2018-10-20 Finished version 1.1.
    [backlight_3x2.sch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]
2018-10-23 Updated documentation for version 1.1.
    [supplemental_digikey_parts.csv]
2018-10-26 Updated supplemental bom.
    [supplemental_digikey_parts.csv]
2018-10-29 high_power -> high_voltage. low_power -> low_voltage.
    [backlight_3x2.sch, backlight_controller_3x2.dsn, backlight_controller_3x2.kicad_pcb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]
2018-10-29 Progress towards v1.2.
    [backlight_3x2.sch, backlight_controller_3x2.kicad_pcb, backlight_controller_3x2.sch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]
2018-10-29 Finished v1.2 schematic.
    [backlight_controller_3x2.kicad_pcb, backlight_output.sch, high_voltage_output.sch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]
2018-10-29 Finished v1.2.
    [backlight_controller_3x2.dsn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]
2021-09-21 Remove ignored files
    [backlight_controller_3x2.dsn]
2022-06-29 power -> user_power
    [backlight_3x2.sch, backlight_controller_3x2.sch, backlight_output.sch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]
